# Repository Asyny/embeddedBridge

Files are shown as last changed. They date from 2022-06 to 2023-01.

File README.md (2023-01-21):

# embeddedBridge

Develop and test your own embedded system without the need to build a dedicated testbench. It is as easy as following three steps:
1. Connect your device under test to the corresponding GPIOs of the embeddedBridge (see: [Features](#Features))
2. Connect the embeddedBridge to your PC
3. Send commands automatically or manually via the serial connection to the embeddedBridge and thus your device

## Features 

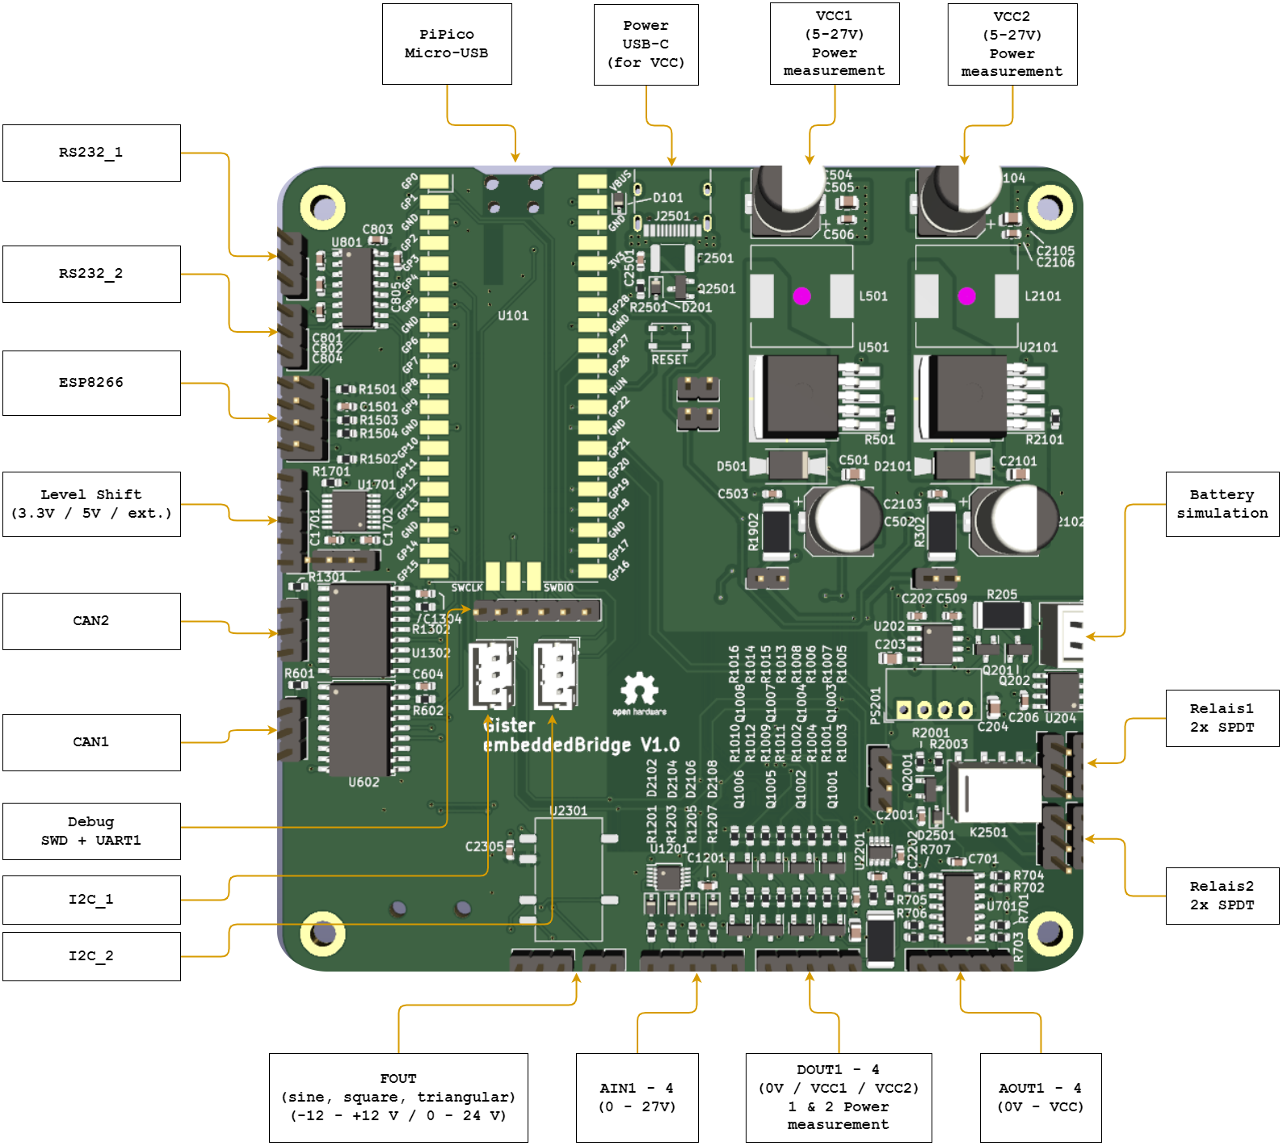
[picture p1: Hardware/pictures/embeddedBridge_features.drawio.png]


- 4x DOUT (2x 0 - 24 V)
- 4x AOUT (0 - 24 V)
- 4x AIN (max. 27 V)
- 1x FOUT
- 2x Relais (2x SPDT)
- 4x Level shift
- 2x RS232
- 2x CAN
- 1x Battery sim
- ESP8266 interface
- SD card
- EEPROM

## Update

- Download the .uf2 from the newest [release](https://github.com/Asyny/embeddedBridge/releases) assets
- Connect the embeddedBridge via micro USB to your PC
- Press the RESET button and the BOOTSEL simultaneously
- Let go of the RESET and afterwards the BOOTSEL button
- Move the .uf2 into the newly connected USB Drive

## Automatic vs Manual mode

The embeddedBridge will start in the automatic mode where it expects SCPI like commands. If you want to switch to the manual mode where a menu is printed on the serial interface, then you can send the command "SYStem:COMmand:INput MENU". To switch back to the automatic mode, you simple need to exit the menu.

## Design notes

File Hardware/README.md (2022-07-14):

# embeddedBridge_HW
THIS PROJECT IS UNDER CONSTRUCTION, IT WILL NOT WORK AS INTENDED!

## Introduction
The embeddedBridge provides an easy way to test your own embedded devices. It comes with an great amount of features with makes it compatible to a lot devices.

This is the Hardware repository. If you are looking fore the Software repository click [here](https://github.com/Asyny/embeddedBridge).

### Features
- based on Raspberry Pi Pico
- 2x variable powersuppies [XL6009]
  - voltage and current measurement [INA219]
- 4x switched output for powersuppies
  - 2x with voltage and current measurement [INA219]
- 1x battery simulation
  - source and sink current [MCP4725]
  - voltage and current measurement [INA219]
- 4x anlog inputs [ADS1115] (16-bit ADC)
- 4x analog ouput [MCP4728] (12-bit DAC)
  - amplified for a max of +24V
- 1x DDS output [AD9833]
  - amplified for a max of +-12V or +24V
  - variable offset [MCP4725]
- 2x CAN [MCP2515]
- 4x digital I/O with level shift
- 2x DPDT Relais
- 2x UART
- 1x ESP8266 header
- 1x SD Card
- 1x 32K EEPROM

## Production
The [Releases](https://github.com/Asyny/embeddedBridge_HW/releases) contain Gerber and Assembly files for [JLCPCB](https://jlcpcb.com/).
An HTML BOM which makes manual assembly easy, is included too.

## Contributing
If you want to contribute, please fork the repo and create a pull request. Thanks for your participation!

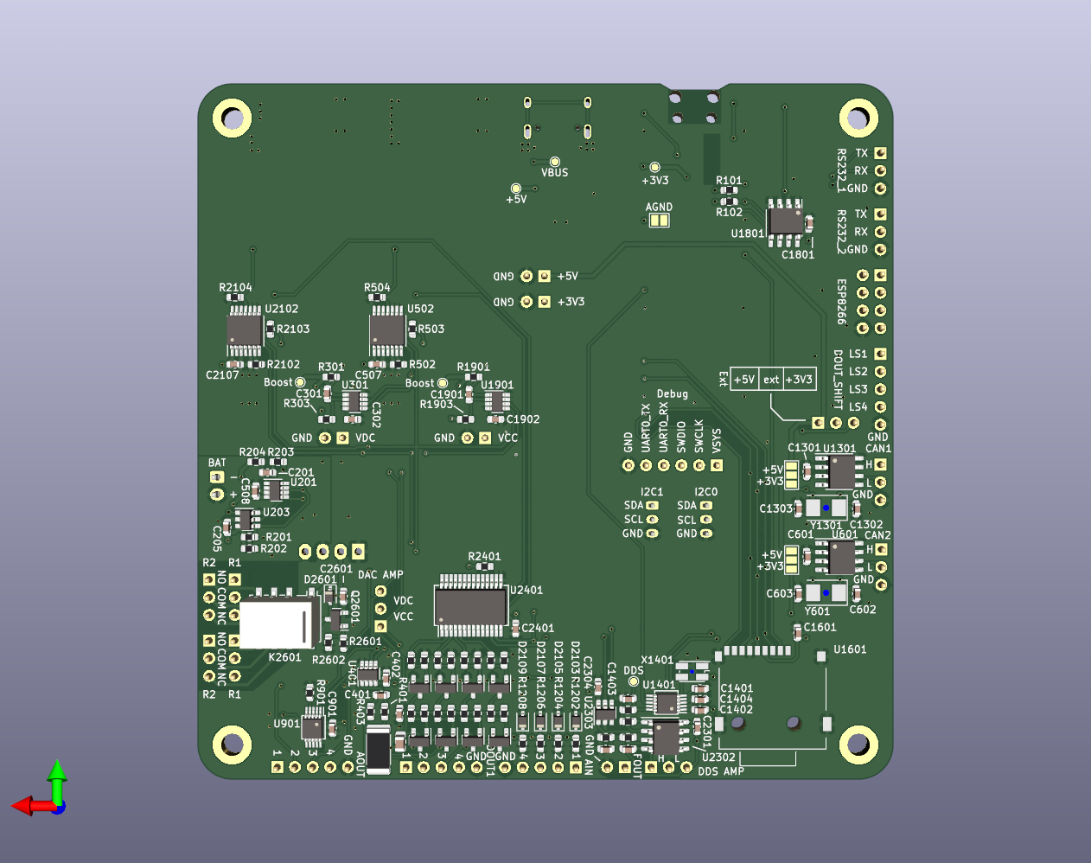
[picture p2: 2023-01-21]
Hardware/pictures/embeddedBridge_back.png

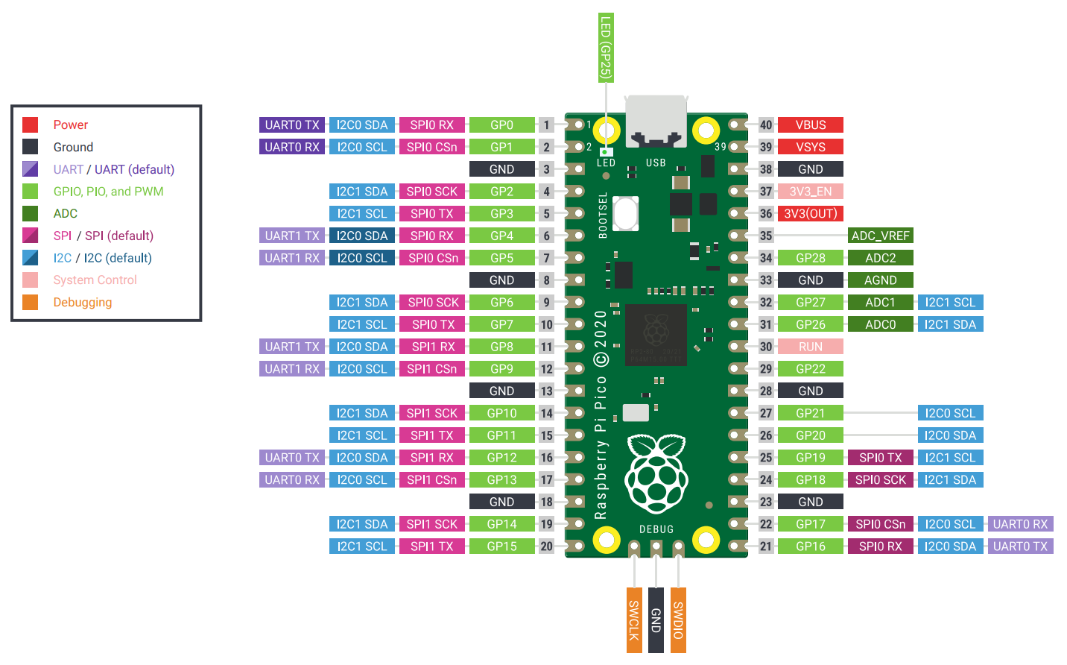
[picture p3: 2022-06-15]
Hardware/pictures/PiPico.PNG

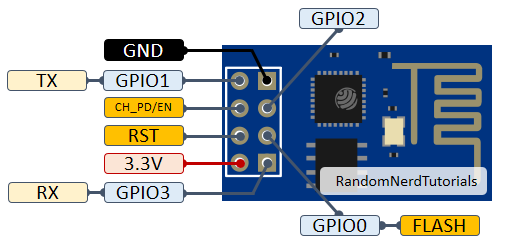
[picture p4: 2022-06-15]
Hardware/pictures/ESP8266-01.PNG

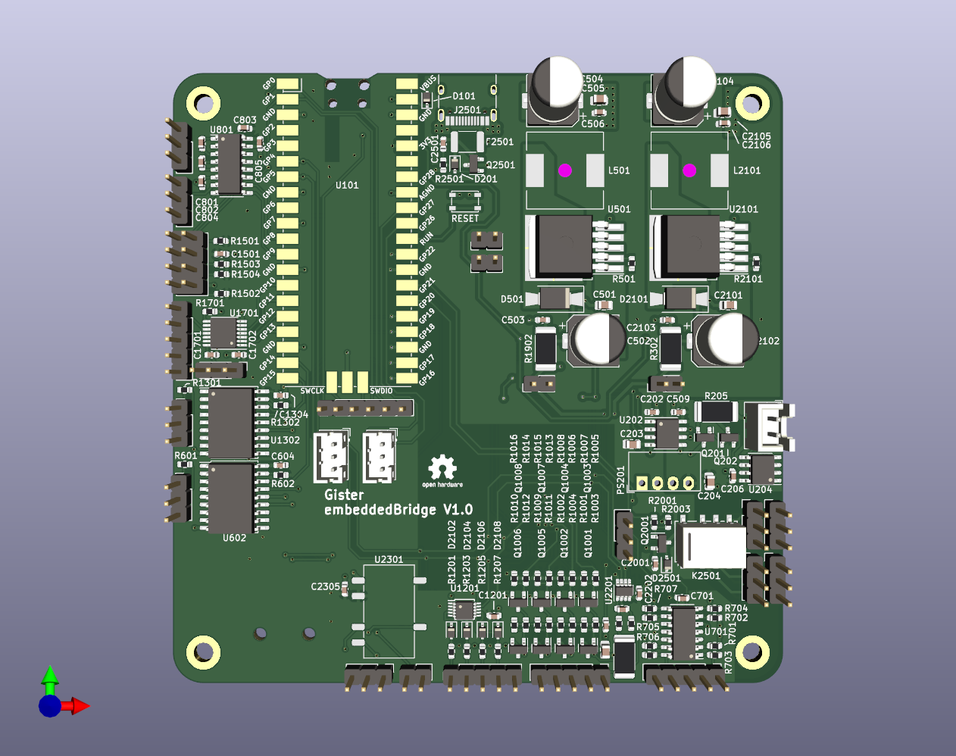
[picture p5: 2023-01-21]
Hardware/pictures/embeddedBridge_front.png

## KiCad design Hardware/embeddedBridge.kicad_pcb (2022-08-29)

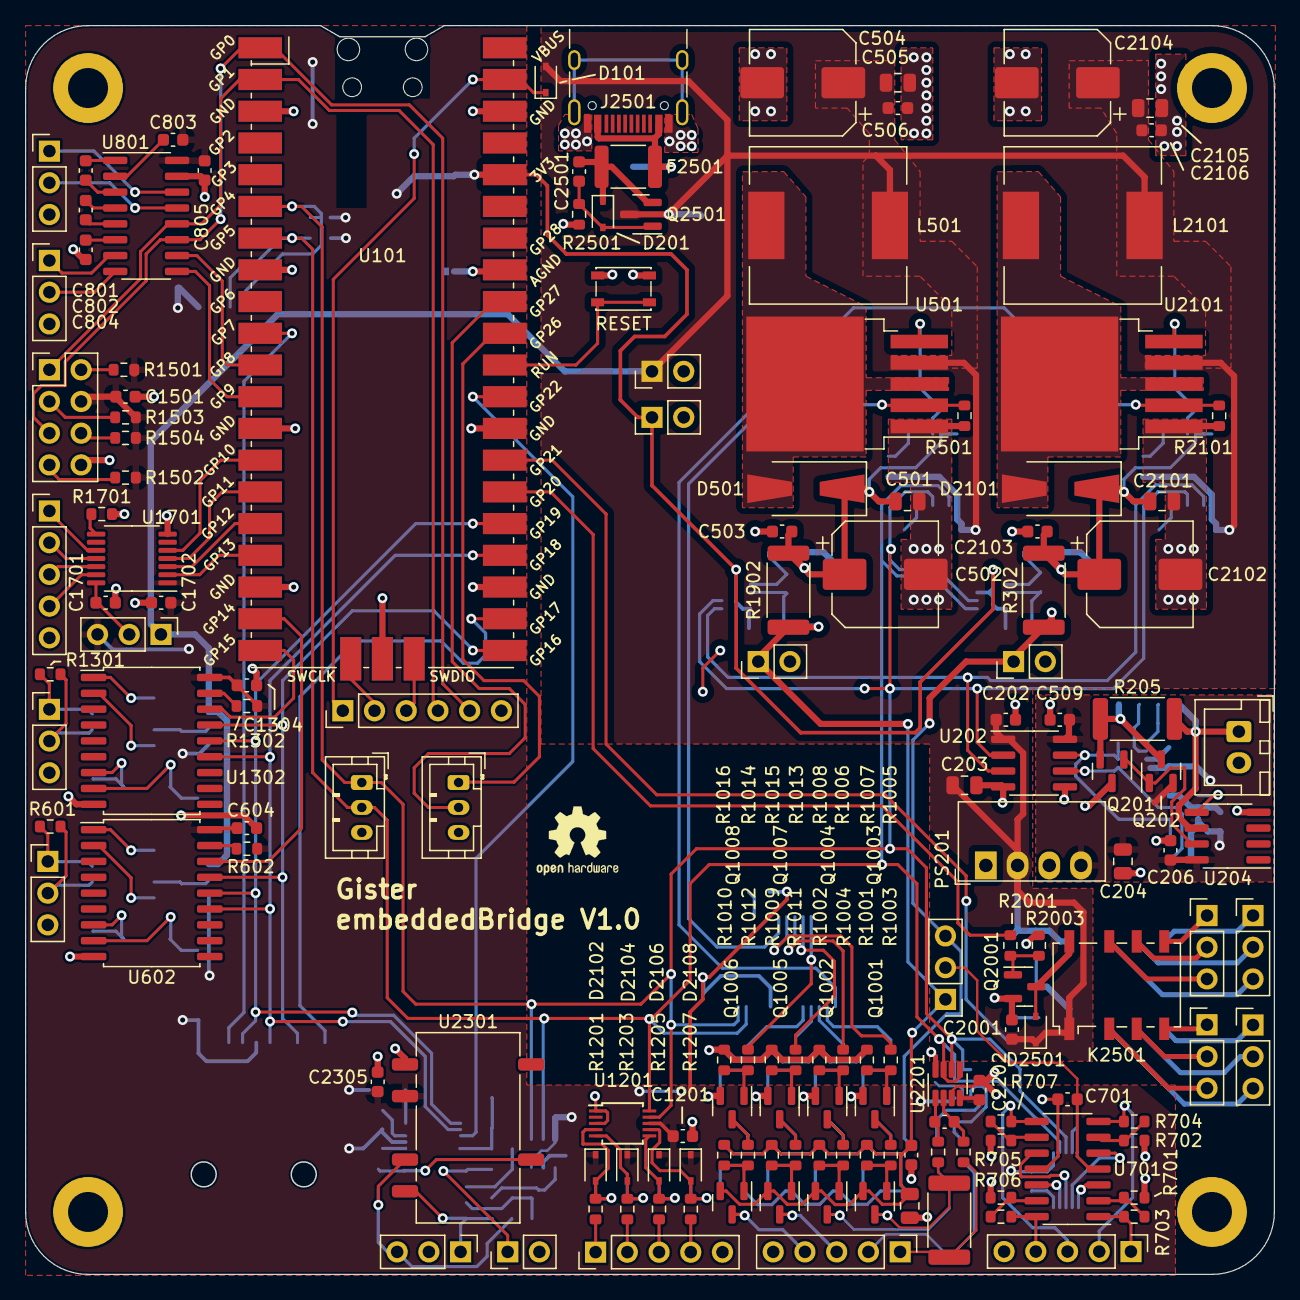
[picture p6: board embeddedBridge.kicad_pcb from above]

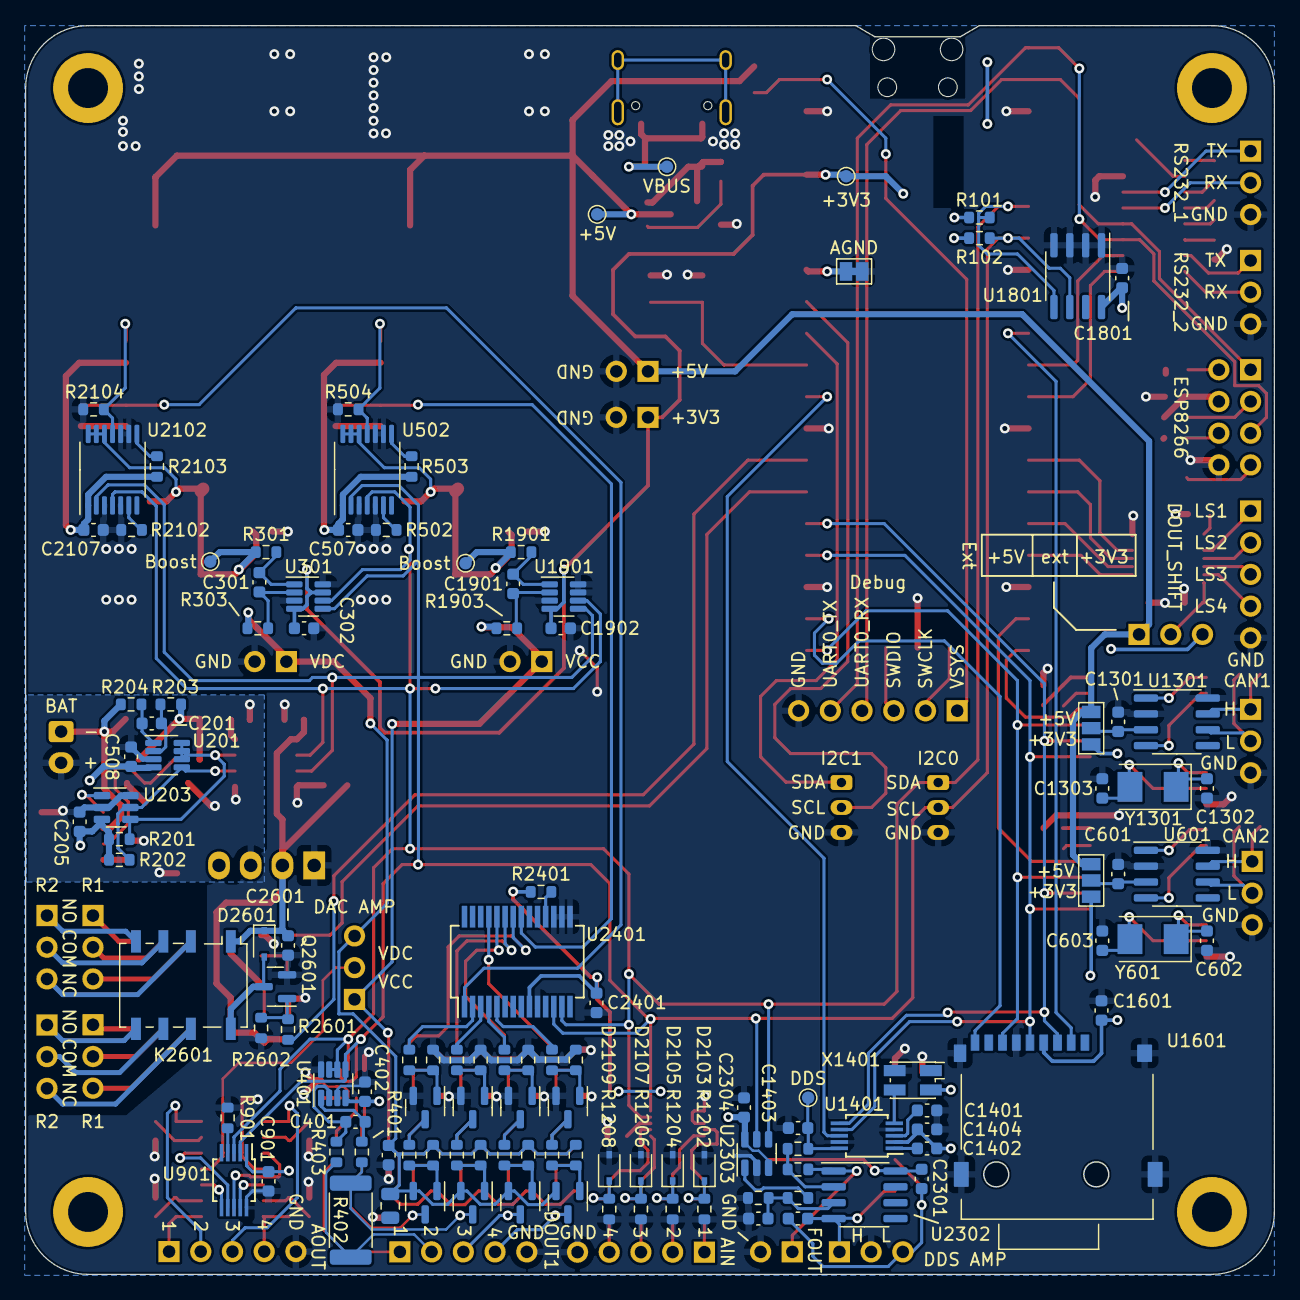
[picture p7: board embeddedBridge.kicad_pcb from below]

Board: 2 copper layers, 100.0 x 100.0 mm, 276 parts (122 on the bottom side), 189 nets.

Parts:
C201, C202, C205, C206, C301, C302, C401, C402, C503, C506, C507, C508, C509, C601, C604, C701, C801, C802, C803, C804, C805, C901, C1001, C1101, C1201, C1301, C1304, C1401, C1404, C1501, C1601, C1701, C1702, C1801, C1901, C1902, C2001, C2103, C2106, C2107, C2201, C2202, C2301, C2302, C2304, C2305, C2401, C2501, C2601: 100n; C_0603_1608Metric
C203, C204, C501, C505, C1002, C1102, C2101, C2105: 1u; C_0805_2012Metric
C502, C2102: 220u; CP_Elec_8x10
C504, C2104: 47u; CP_Elec_8x10
C602, C603, C1302, C1303: 22p; C_0603_1608Metric
C1402: 10n; C_0603_1608Metric
C1403: 20p; C_0603_1608Metric
C2303: 680n; C_0603_1608Metric
D101, D201, D2102, D2103, D2104, D2105, D2106, D2107, D2108, D2109, D2501, D2601: 1N5819; D_SOD-323
D501, D2101: D_Schottky; D_SMA-SMB_Universal_Handsoldering
F2501: Polyfuse; Fuse_1812_4532Metric
H101, H102, H103, H104: MountingHole_Pad; MountingHole_3.2mm_M3_DIN965_Pad
J101: AOUT; PinHeader_1x05_P2.54mm_Vertical
J102: I2C1; JST_PH_B3B-PH-K_1x03_P2.00mm_Vertical
J103: I2C0; JST_PH_B3B-PH-K_1x03_P2.00mm_Vertical
J104: Debug; PinHeader_1x06_P2.54mm_Vertical
J105: VCC; PinHeader_1x02_P2.54mm_Vertical
J106: DOUT1; PinHeader_1x05_P2.54mm_Vertical
J107: FOUT; PinHeader_1x02_P2.54mm_Vertical
J108: CAN1; PinHeader_1x03_P2.54mm_Vertical
J109: CAN2; PinHeader_1x03_P2.54mm_Vertical
J110: VDC; PinHeader_1x02_P2.54mm_Vertical
J111: R1_1; PinHeader_1x03_P2.54mm_Vertical
J112: R1_2; PinHeader_1x03_P2.54mm_Vertical
J113: R2_1; PinHeader_1x03_P2.54mm_Vertical
J114: R2_2; PinHeader_1x03_P2.54mm_Vertical
J115: RS232_2; PinHeader_1x03_P2.54mm_Vertical
J116: RS232_1; PinHeader_1x03_P2.54mm_Vertical
J117: +3V3; PinHeader_1x02_P2.54mm_Vertical
J118: +5V; PinHeader_1x02_P2.54mm_Vertical
J201: BAT; JST_XH_B2B-XH-A_1x02_P2.50mm_Vertical
J1201: AIN; PinHeader_1x05_P2.54mm_Vertical
J1501: ESP8266; PinHeader_2x04_P2.54mm_Vertical
J1701: DOUT_SHIFT; PinHeader_1x05_P2.54mm_Vertical
J2501: USB_C_Receptacle_USB2.0; USB_C_Receptacle_HRO_TYPE-C-31-M-12
JP101: AGND; SolderJumper-2_P1.3mm_Bridged_Pad1.0x1.5mm
JP601, JP1301: SolderJumper_3_Open; SolderJumper-3_P1.3mm_Open_Pad1.0x1.5mm_NumberLabels
JP701: DAC AMP; PinHeader_1x03_P2.54mm_Vertical
JP1701: Ext; PinHeader_1x03_P2.54mm_Vertical
JP2301: DDS AMP; PinHeader_1x03_P2.54mm_Vertical
K2501, K2601: G6K-2F-Y; Relay_DPDT_Omron_G6K-2F-Y
L501, L2101: 33uH; L_12x12mm_H8mm
PS201: 1S4E_0505S1U; Converter_DCDC_Murata_MEE1SxxxxSC_THT
Q201: Q_NPN_BCE; SOT-23
Q202: Q_PNP_BCE; SOT-23
Q1001, Q1002, Q1005, Q1006, Q1101, Q1102, Q1105, Q1106, Q2501: Q_PMOS_GSD; SOT-23
Q1003, Q1004, Q1007, Q1008, Q1103, Q1104, Q1107, Q1108: MMBT3904; SOT-23
Q2001, Q2601: Q_NMOS_GSD; SOT-23
R101, R102, R201, R202, R901, R2301: 4k7; R_0603_1608Metric
R203, R204, R301, R303, R401, R403, R1901, R1903, R2201, R2203: 10R; R_0603_1608Metric
R205, R302, R402, R1902, R2202: 100R; R_2512_6332Metric
R501, R502, R503, R602, R701, R702, R705, R706, R1001, R1002, R1005, R1006, R1009, R1010, R1013, R1014, R1101, R1102, R1105, R1106, R1109, R1110, R1113, R1114, R1302, R1501, R1502, R1503, R1504, R1701, R2001, R2101, R2102, R2103, R2304, R2401, R2601: 10k; R_0603_1608Metric
R504, R2104: 470R; R_0603_1608Metric
R601, R1301: 120R; R_0603_1608Metric
R703, R704, R707, R708: 68k; R_0603_1608Metric
R1003, R1004, R1007, R1008, R1011, R1012, R1015, R1016, R1103, R1104, R1107, R1108, R1111, R1112, R1115, R1116, R2003, R2501, R2602: 100k; R_0603_1608Metric
R1201, R1203, R1205, R1207: 12k; R_0603_1608Metric
R1202, R1204, R1206, R1208: 1k5; R_0603_1608Metric
R2302: 39k; R_0603_1608Metric
R2303: 1k; R_0603_1608Metric
SW101: RESET; SW_SPST_PTS810
TP101: +3V3; TestPoint_Pad_D1.0mm
TP102: DDS; TestPoint_Pad_D1.0mm
TP201: VBUS; TestPoint_Pad_D1.0mm
TP202: +5V; TestPoint_Pad_D1.0mm
TP501, TP2101: Boost; TestPoint_Pad_D1.0mm
U101: Pico; RPi_Pico_SMD_TH
U201, U301, U401, U1901, U2201: INA219AxDCN; SOT-23-8
U202: ISO1540; SOIC-8_3.9x4.9mm_P1.27mm
U203, U2303: MCP4725xxx-xCH; SOT-23-6
U204, U2302: Opamp_Dual; SOIC-8_3.9x4.9mm_P1.27mm
U501, U2101: XL6009; TO-263-5_TabPin3
U502, U2102: MCP45HV31-ST; TSSOP-14_4.4x5mm_P0.65mm
U601, U1301: TJA1051T-3; SOIC-8_3.9x4.9mm_P1.27mm
U602, U1302: MCP2515-xSO; SOIC-18W_7.5x11.6mm_P1.27mm
U701: LM324; SOIC-14_3.9x8.7mm_P1.27mm
U801: MAX3232; SOIC-16_3.9x9.9mm_P1.27mm
U901: MCP4728; MSOP-10_3x3mm_P0.5mm
U1201: ADS1115IDGS; TSSOP-10_3x3mm_P0.5mm
U1401: AD9833xRM; MSOP-10_3x3mm_P0.5mm
U1601: TF-01A; FT-01A
U1701: TXB0104PW; TSSOP-14_4.4x5mm_P0.65mm
U1801: 24LC32; SOIC-8_3.9x4.9mm_P1.27mm
U2301: PDS1-M; PSD1
U2401: MCP23017_SS; SSOP-28_5.3x10.2mm_P0.65mm
X1401: XO32; Oscillator_SMD_EuroQuartz_XO32-4Pin_3.2x2.5mm_HandSoldering
Y601, Y1301: 8MHz; Crystal_SMD_5032-2Pin_5.0x3.2mm

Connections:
+3V3: C302.1, C402.1, C604.1, C803.1, C805.1, C901.1, C1201.1, C1304.1, C1402.1, C1404.1, C1501.1, C1601.1, C1702.1, C1801.1, C1902.1, C2202.1, C2304.1, C2305.1, C2401.1, D2102.1 (K), D2104.1 (K), D2106.1 (K), D2108.1 (K), J117.1, J1501.4, JP601.1 (A), JP1301.1 (A), JP1701.3 (B), R101.2, R102.2, R602.1, R1302.1, R1501.1, R1502.1, R1503.2, R1504.2, R2401.1, TP101.1, U101.36 (3V3), U301.4 (VS), U301.7 (A0), U401.4 (VS), U602.18 (VDD), U801.16 (VCC), U901.1 (VDD), U1201.8 (VDD), U1302.18 (VDD), U1401.2 (VDD), U1601.4 (VDD), U1701.1 (VCCA), U1801.8 (VCC), U1901.4 (VS), U2201.4 (VS), U2301.2 (Vin), U2303.3 (VDD), U2303.6 (A0), U2401.9 (VDD), X1401.4 (V+)
+5V: C202.1, C203.1, C504.1, C505.1, C506.1, C507.1, C2001.1, C2104.1, C2105.1, C2106.1, C2107.1, C2601.1, D101.2 (A), D2501.1 (K), D2601.1 (K), J118.1, JP601.3 (B), JP1301.3 (B), JP1701.1 (A), K2501.1, K2601.1, L501.1, L2101.1, PS201.2 (+Vin), Q2501.3 (D), R503.2, R2103.2, TP202.1, U202.1 (VCC1), U501.4 (VIN), U502.1 (VL), U2101.4 (VIN), U2102.1 (VL)
+5VD: C204.1, C205.1, C206.1, C508.1, C509.1, PS201.4 (+Vout), Q201.2 (C), R201.1, R202.1, U201.4 (VS), U202.8 (VCC2), U203.3 (VDD), U204.8 (V+)
/AMP1/IN1+: U701.3 (+), U901.6 (VOUTA)
/AMP1/IN2+: U701.5 (+), U901.7 (VOUTB)
/AMP1/IN3+: U701.10 (+), U901.8 (VOUTC)
/AMP1/IN4+: U701.12 (+), U901.9 (VOUTD)
/AMP1/OUT1: J101.1, R703.2, U701.1
/AMP1/OUT2: J101.2, R704.2, U701.7
/AMP1/OUT3: J101.3, R707.2, U701.8
/AMP1/OUT4: J101.4, R708.2, U701.14
/AMP_offset/IN: C1403.1, R2301.2, TP102.1, U1401.10 (VOUT)
/AMP_offset/OUT: J107.1, R2302.2, U2302.1
/Battery/BAT+: J201.1, R204.1, R205.2, U204.6 (-)
/Battery/BAT+_: Q201.3 (E), Q202.2 (C), R203.1, R205.1
/Battery/SCL_: R202.2, U201.5 (SCL), U202.6 (SCL2), U203.5 (SCL)
/Battery/SDA_: R201.2, U201.6 (SDA), U201.7 (A0), U201.8 (A1), U202.7 (SDA2), U203.4 (SDA)
/CAN1/CANH: J108.1, R1301.2, U1301.7 (CANH)
/CAN1/CANL: J108.2, R1301.1, U1301.6 (CANL)
/CAN2/CANH: J109.1, R601.2, U601.7 (CANH)
/CAN2/CANL: J109.2, R601.1, U601.6 (CANL)
/CD_SD: U101.22 (GPIO17), U1601.9 (CD)
/Cu1+: C501.1, C502.1, C503.1, D501.1 (K), R1901.1, R1902.1, TP501.1, U502.12 (P0W), U502.13 (P0A), U502.14 (V+)
/Cu2+: C2101.1, C2102.1, C2103.1, D2101.1 (K), R301.1, R302.1, TP2101.1, U2102.12 (P0W), U2102.13 (P0A), U2102.14 (V+)
/Cu3+: Q1002.3 (D), Q1102.3 (D), R401.1, R402.1
/Cu3-: J106.2, R402.2, R403.1
/Cu4+: Q1001.3 (D), Q1101.3 (D), R2201.1, R2202.1
/Cu4-: J106.1, R2202.2, R2203.1
/DAC1/LDAC: R901.1, U901.4 (~LDAC)
/DOUT1_LS: U101.14 (GPIO10), U1701.5 (A4)
/DOUT2_LS: U101.15 (GPIO11), U1701.4 (A3)
/DOUT3_LS: U101.16 (GPIO12), U1701.3 (A2)
/DOUT4_LS: U101.17 (GPIO13), U1701.2 (A1)
/ESP8266/EN: J1501.2, R1501.2
/ESP8266/IO0: J1501.6, R1504.1
/ESP8266/IO2: J1501.7, R1502.2
/ESP8266/RST: J1501.3, R1503.1
/I2C0_SCL: J103.2, R102.1, U101.7 (GPIO5), U202.3 (SCL1), U301.5 (SCL), U401.5 (SCL), U502.2 (SCL), U901.2 (SCL), U1201.10 (SCL), U1801.6 (SCL), U1901.5 (SCL), U2102.2 (SCL), U2201.5 (SCL), U2201.7 (A0), U2303.5 (SCL), U2401.12 (SCK)
/I2C0_SDA: J103.1, R101.1, U101.6 (GPIO4), U202.2 (SDA1), U301.6 (SDA), U401.6 (SDA), U401.7 (A0), U502.4 (SDA), U901.3 (SDA), U1201.9 (SDA), U1801.5 (SDA), U1901.6 (SDA), U2102.4 (SDA), U2201.6 (SDA), U2303.4 (SDA), U2401.13 (SDA)
/I2C1_SCL: J102.2, U101.32 (GPIO27_ADC1)
/I2C1_SDA: J102.1, U101.31 (GPIO26_ADC0)
/IO_Expander/GPA1: R1005.1, U2401.22 (GPA1)
/IO_Expander/GPA2: R1006.1, U2401.23 (GPA2)
/IO_Expander/GPA3: R1013.1, U2401.24 (GPA3)
/IO_Expander/GPA4: R1014.1, U2401.25 (GPA4)
/IO_Expander/GPB1: R1105.1, U2401.2 (GPB1)
/IO_Expander/GPB2: R1106.1, U2401.3 (GPB2)
/IO_Expander/GPB3: R1113.1, U2401.4 (GPB3)
/IO_Expander/GPB4: R1114.1, U2401.5 (GPB4)
/Level Shift/OE: R1701.1, U1701.8 (OE)
/Power1/FB: R504.1, U501.5 (FB), U502.11 (P0B)
/Power1/SW: D501.2 (A), L501.2, U501.3 (SW)
/Power2/FB: R2104.1, U2101.5 (FB), U2102.11 (P0B)
/Power2/SW: D2101.2 (A), L2101.2, U2101.3 (SW)
/RUN: SW101.1 (A), U101.30 (RUN)
/Relais1: R2001.1, U101.26 (GPIO20)
/Relais1/COM1: J111.2, K2501.3
/Relais1/COM2: J112.2, K2501.6
/Relais1/NC1: J111.3, K2501.2
/Relais1/NC2: J112.3, K2501.7
/Relais1/NO1: J111.1, K2501.4
/Relais1/NO2: J112.1, K2501.5
/Relais2: R2601.1, U101.27 (GPIO21)
/Relais2/COM1: J113.2, K2601.3
/Relais2/COM2: J114.2, K2601.6
/Relais2/NC1: J113.3, K2601.2
/Relais2/NC2: J114.3, K2601.7
/Relais2/NO1: J113.1, K2601.4
/Relais2/NO2: J114.1, K2601.5
/SPI0_CS_CAN1: U101.20 (GPIO15), U1302.16 (~CS)
/SPI0_CS_CAN2: U101.19 (GPIO14), U602.16 (~CS)
/SPI0_CS_DDS: U101.29 (GPIO22), U1401.8 (~FSYNC)
/SPI0_CS_SD: U101.10 (GPIO7), U1601.2 (CDDAT3(CS))
/SPI0_MISO: U101.21 (GPIO16), U602.15 (SO), U1302.15 (SO), U1601.7 (DAT0(D0))
/SPI0_MOSI: U101.25 (GPIO19), U602.14 (SI), U1302.14 (SI), U1401.6 (SDATA), U1601.3 (CMD(DI))
/SPI0_SCK: U101.24 (GPIO18), U602.13 (SCK), U1302.13 (SCK), U1401.7 (SCLK), U1601.5 (CLK(SCLK))
/SWCLK: J104.2, U101.41 (SWCLK)
/SWDIO: J104.3, U101.43 (SWDIO)
/Switch1/DOUT3: J106.3, Q1005.3 (D), Q1105.3 (D)
/Switch1/DOUT4: J106.4, Q1006.3 (D), Q1106.3 (D)
/UART0_RX: J104.4, J1501.1, U101.2 (GPIO1), U801.12 (R1OUT)
/UART0_TX: J104.5, J1501.5, U101.1 (GPIO0), U801.11 (T1IN)
/UART1_RX: U101.12 (GPIO9), U801.9 (R2OUT)
/UART1_TX: U101.11 (GPIO8), U801.10 (T2IN)
/UART to RS232/RX1: J116.2, U801.13 (R1IN)
/UART to RS232/RX2: J115.2, U801.8 (R2IN)
/UART to RS232/TX1: J116.1, U801.14 (T1OUT)
/UART to RS232/TX2: J115.1, U801.7 (T2OUT)
/USB/VBUS: F2501.1, J2501.A4 (VBUS), J2501.A9 (VBUS), J2501.B4 (VBUS), J2501.B9 (VBUS), TP201.1
/USB/VBUS_FUSED: C2501.1, D201.1 (K), F2501.2, Q2501.2 (S)
/VCC_EN: R501.1, U501.2 (EN), U2401.21 (GPA0)
/VDC_EN: R2101.1, U2101.2 (EN), U2401.1 (GPB0)
/VSYS: D101.1 (K), J104.1, U101.39 (VSYS)
GND: C202.2, C203.2, C302.2, C402.2, C501.2, C502.2, C503.2, C504.2, C505.2, C506.2, C507.2, C601.2, C602.2, C603.2, C604.2, C701.2, C804.1, C805.2, C901.2, C1001.2, C1002.2, C1101.2, C1102.2, C1201.2, C1301.2, C1302.2, C1303.2, C1304.2, C1401.2, C1403.2, C1404.2, C1501.2, C1601.2, C1701.2, C1702.2, C1801.2, C1902.2, C2001.2, C2101.2, C2102.2, C2103.2, C2104.2, C2105.2, C2106.2, C2107.2, C2202.2, C2303.2, C2304.2, C2305.2, C2401.2, C2601.2, D2103.2 (A), D2105.2 (A), D2107.2 (A), D2109.2 (A), J101.5, J102.3, J103.3, J104.6, J105.2, J106.5, J107.2, J108.3, J109.3, J110.2, J115.3, J116.3, J117.2, J118.2, J1201.5, J1501.8, J1701.5, J2501.A1 (GND), J2501.A12 (GND), J2501.B1 (GND), J2501.B12 (GND), JP101.1 (A), JP2301.2 (C), PS201.1 (-Vin), Q1003.2 (E), Q1004.2 (E), Q1007.2 (E), Q1008.2 (E), Q1103.2 (E), Q1104.2 (E), Q1107.2 (E), Q1108.2 (E), Q2001.2 (S), Q2601.2 (S), R501.2, R502.2, R504.2, R701.1, R702.1, R705.1, R706.1, R901.2, R1007.2, R1008.2, R1015.2, R1016.2, R1107.2, R1108.2, R1115.2, R1116.2, R1202.2, R1204.2, R1206.2, R1208.2, R1701.2, R2003.2, R2101.2, R2102.2, R2104.2, R2304.2, R2501.2, R2602.2, SW101.2 (B), U101.3 (GND), U101.8 (GND), U101.13 (GND), U101.18 (GND), U101.23 (GND), U101.28 (GND), U101.38 (GND), U101.42 (GND), U202.4 (GND1), U301.3 (GND), U301.8 (A1), U401.3 (GND), U401.8 (A1), U501.1 (GND), U502.3 (A1), U502.5 (A0), U502.9 (DGND), U502.10 (V-), U601.2 (GND), U601.8 (S), U602.9 (VSS), U701.11 (V-), U801.15 (GND), U901.10 (VSS), U1201.1 (ADDR), U1201.3 (GND), U1301.2 (GND), U1301.8 (S), U1302.9 (VSS), U1401.4 (DGND), U1401.9 (AGND), U1601.6 (VSS), U1601.10 (GND), U1601.11 (GND), U1601.12 (GND), U1601.13 (GND), U1701.7 (GND), U1801.1 (A0), U1801.2 (A1), U1801.3 (A2), U1801.4 (GND), U1901.3 (GND), U1901.7 (A0), U1901.8 (A1), U2101.1 (GND), U2102.3 (A1), U2102.5 (A0), U2102.9 (DGND), U2102.10 (V-), U2201.3 (GND), U2201.8 (A1), U2301.1 (GND), U2303.2 (VSS), U2401.10 (VSS), U2401.15 (A0), U2401.16 (A1), U2401.17 (A2), X1401.2 (GND)
GNDA: JP101.2 (B), U101.33 (AGND)
GNDD: C204.2, C205.2, C206.2, C508.2, C509.2, J201.2, PS201.3 (-Vout), Q202.3 (E), U201.3 (GND), U202.5 (GND2), U203.2 (VSS), U203.6 (A0), U204.4 (V-)
unnamed: C201.1, R203.2, U201.2 (IN-)
unnamed: C201.2, R204.2, U201.1 (IN+)
unnamed: C301.1, R301.2, U301.1 (IN+)
unnamed: C301.2, R303.2, U301.2 (IN-)
unnamed: C401.1, R401.2, U401.1 (IN+)
unnamed: C401.2, R403.2, U401.2 (IN-)
unnamed: C601.1, JP601.2 (C), U601.3 (VCC)
unnamed: C602.1, U602.7 (OSC2), Y601.1
unnamed: C603.1, U602.8 (OSC1), Y601.2
unnamed: C701.1, JP701.2 (C), U701.4 (V+)
unnamed: C801.1, U801.3 (C1-)
unnamed: C801.2, U801.1 (C1+)
unnamed: C802.1, U801.5 (C2-)
unnamed: C802.2, U801.4 (C2+)
unnamed: C803.2, U801.2 (VS+)
unnamed: C804.2, U801.6 (VS-)
unnamed: C1301.1, JP1301.2 (C), U1301.3 (VCC)
unnamed: C1302.1, U1302.7 (OSC2), Y1301.1
unnamed: C1303.1, U1302.8 (OSC1), Y1301.2
unnamed: C1401.1, U1401.3 (CAP/2.5V)
unnamed: C1402.2, U1401.1 (COMP)
unnamed: C1701.1, JP1701.2 (C), U1701.14 (VCCB)
unnamed: C1901.1, R1901.2, U1901.1 (IN+)
unnamed: C1901.2, R1903.2, U1901.2 (IN-)
unnamed: C2201.1, R2201.2, U2201.1 (IN+)
unnamed: C2201.2, R2203.2, U2201.2 (IN-)
unnamed: C2301.1, U2301.7 (+Vo), U2302.8 (V+)
unnamed: C2301.2, C2302.1, JP2301.3 (B), U2301.4 (0V)
unnamed: C2302.2, JP2301.1 (A), U2301.5 (-Vo), U2302.4 (V-)
unnamed: C2303.1, R2303.1, R2304.1, U2302.3 (+)
unnamed: C2501.2, D201.2 (A), Q2501.1 (G), R2501.1
unnamed: D2102.2 (A), D2103.1 (K), R1201.2, R1202.1, U1201.4 (AIN0)
unnamed: D2104.2 (A), D2105.1 (K), R1203.2, R1204.1, U1201.5 (AIN1)
unnamed: D2106.2 (A), D2107.1 (K), R1205.2, R1206.1, U1201.6 (AIN2)
unnamed: D2108.2 (A), D2109.1 (K), R1207.2, R1208.1, U1201.7 (AIN3)
unnamed: D2501.2 (A), K2501.8, Q2001.3 (D)
unnamed: D2601.2 (A), K2601.8, Q2601.3 (D)
unnamed: J1201.1, R1201.1
unnamed: J1201.2, R1203.1
unnamed: J1201.3, R1205.1
unnamed: J1201.4, R1207.1
unnamed: J1701.1, U1701.10 (B4)
unnamed: J1701.2, U1701.11 (B3)
unnamed: J1701.3, U1701.12 (B2)
unnamed: J1701.4, U1701.13 (B1)
unnamed: Q201.1 (B), Q202.1 (B), U204.7
unnamed: Q1001.1 (G), R1001.2, R1003.1
unnamed: Q1002.1 (G), R1002.2, R1004.1
unnamed: Q1003.1 (B), R1005.2, R1007.1
unnamed: Q1003.3 (C), R1003.2
unnamed: Q1004.1 (B), R1006.2, R1008.1
unnamed: Q1004.3 (C), R1004.2
unnamed: Q1005.1 (G), R1009.2, R1011.1
unnamed: Q1006.1 (G), R1010.2, R1012.1
unnamed: Q1007.1 (B), R1013.2, R1015.1
unnamed: Q1007.3 (C), R1011.2
unnamed: Q1008.1 (B), R1014.2, R1016.1
unnamed: Q1008.3 (C), R1012.2
unnamed: Q1101.1 (G), R1101.2, R1103.1
unnamed: Q1102.1 (G), R1102.2, R1104.1
unnamed: Q1103.1 (B), R1105.2, R1107.1
unnamed: Q1103.3 (C), R1103.2
unnamed: Q1104.1 (B), R1106.2, R1108.1
unnamed: Q1104.3 (C), R1104.2
unnamed: Q1105.1 (G), R1109.2, R1111.1
unnamed: Q1106.1 (G), R1110.2, R1112.1
unnamed: Q1107.1 (B), R1113.2, R1115.1
unnamed: Q1107.3 (C), R1111.2
unnamed: Q1108.1 (B), R1114.2, R1116.1
unnamed: Q1108.3 (C), R1112.2
unnamed: Q2001.1 (G), R2001.2, R2003.1
unnamed: Q2601.1 (G), R2601.2, R2602.1
unnamed: R502.1, U502.6 (~WLAT)
unnamed: R503.1, U502.8 (~SHDN)
unnamed: R602.2, U602.17 (~RESET)
unnamed: R701.2, R703.1, U701.2 (-)
unnamed: R702.2, R704.1, U701.6 (-)
unnamed: R705.2, R707.1, U701.9 (-)
unnamed: R706.2, R708.1, U701.13 (-)
unnamed: R1302.2, U1302.17 (~RESET)
unnamed: R2102.1, U2102.6 (~WLAT)
unnamed: R2103.1, U2102.8 (~SHDN)
unnamed: R2301.1, R2302.1, U2302.2 (-)
unnamed: R2303.2, U2303.1 (VOUT)
unnamed: R2401.2, U2401.18 (~RESET)
unnamed: U203.1 (VOUT), U204.5 (+)
unnamed: U601.1 (TXD), U602.1 (TXCAN)
unnamed: U601.4 (RXD), U602.2 (RXCAN)
unnamed: U1301.1 (TXD), U1302.1 (TXCAN)
unnamed: U1301.4 (RXD), U1302.2 (RXCAN)
unnamed: U1401.5 (MCLK), X1401.3 (OUT)
VCC: C1001.1, C1002.1, J105.1, JP701.1 (A), Q1001.2 (S), Q1002.2 (S), Q1005.2 (S), Q1006.2 (S), R1001.1, R1002.1, R1009.1, R1010.1, R1902.2, R1903.1
VDC: C1101.1, C1102.1, J110.1, JP701.3 (B), Q1101.2 (S), Q1102.2 (S), Q1105.2 (S), Q1106.2 (S), R302.2, R303.1, R1101.1, R1102.1, R1109.1, R1110.1

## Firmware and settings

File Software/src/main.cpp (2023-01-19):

#include <Arduino.h>

// custom libraries
#include "hardware.h"
#include "HAL.h"

#include "CommandHandling/CommandHandler.h"
#include "CommandHandling/InteractiveCommandHandler.h"
#include "CommandHandling/ScpiCommandHandler.h"

#include "DataHandling/DataHandler.h"


CommandHandler* commandHandler = nullptr;
DataHandler* dataHandler = nullptr;

void setup() {
	Debug.setDebugLevel(DEBUG_LEVEL);
	Debug.setDebugOutputStream(&DEBUG_SERIAL);

	HAL::getInstance()->initialize();

	commandHandler = new ScpiCommandHandler();
	dataHandler = new DataHandler();

	Debug.print(DBG_INFO, "\n>>> init done");
}

void selectCommandMenuSource(void) {
	if (DataModel::newMode != DataModel::CommandHandlerInputMode::IDLE) {
		if (commandHandler != nullptr)
				delete commandHandler;

		if (DataModel::newMode == DataModel::CommandHandlerInputMode::INTERACTIVE) {
			commandHandler = new SerialMenu::InteractiveCommandHandler();
		}
		else if (DataModel::newMode == DataModel::CommandHandlerInputMode::SCPI) {
			commandHandler = new ScpiCommandHandler();
		}

		commandHandler->setup();
		DataModel::newMode = DataModel::CommandHandlerInputMode::IDLE;
	}
}

void loop() {
	selectCommandMenuSource();

	commandHandler->process();
	dataHandler->process();
}

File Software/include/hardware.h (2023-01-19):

#ifndef HARDWARE_H
#define HARDWARE_H

// third party libraries
#include <Arduino.h>
#include <Arduino_DebugUtils.h>

#define DEBUG_SERIAL Serial1
#define DEBUG_LEVEL DBG_WARNING	// DBG_NONE, DBG_ERROR, DBG_WARNING, DBG_INFO, DBG_DEBUG, DBG_VERBOSE

// datasheets
//MCP45HV31 https://eu.mouser.com/datasheet/2/268/20005304A-347268.pdf

// Serial
#define SERIAL_BAUD 115200
// UART
#define UART0_BAUD 115200
#define UART0_TX 0
#define UART0_RX 1
#define UART1_BAUD 115200
#define UART1_TX 8
#define UART1_RX 9

// SPI
#define SPI0_SCK 18
#define SPI0_MOSI 19
#define SPI0_MISO 16
// SPI CS
#define AD9833_DDS_CS 22
#define MCP2515_CAN1_CS 15
#define MCP2515_CAN2_CS 14
#define SD_CS 7

// GPIOs
#define LED_PIN 25
#define RELAIS1_PIN 20
#define RELAIS2_PIN 21
#define LEVELSHIFT1_PIN 10
#define LEVELSHIFT2_PIN 11
#define LEVELSHIFT3_PIN 12
#define LEVELSHIFT4_PIN 13
#define AMP_HL 3
#define SD_CD 17

// I2C
#define I2C0_SDA 4
#define I2C0_SCL 5
#define I2C1_SDA 26
#define I2C1_SCL 27
// I2C Adresses
#define INA219_VCC_ADDR 0x40
#define INA219_VDC_ADDR 0x41
#define INA219_DOUT1_ADDR 0x42
#define INA219_DOUT2_ADDR 0x43
#define INA219_BAT_ADDR 0x4A
#define MCP23017_DOUT_ADDR 0x20	
//#define MCP4728_AOUT_ADDR 0x60	// ToDo: BUG same adress as MCP4725 Battery
#define MCP4725_BAT_ADDR 0x60 // AJxx=110000n, APxx=110001n, AQxx=110010n, ARxx=110011n
#define MCP4725_DDSOFFSET_ADDR 0x61
#define ADS1115_AIN_ADDR 0x48
#define EEPROM_ADDR 0x50
#define MCP45HV31_VCC_ADDR 0x3C
#define MCP45HV31_VDC_ADDR 0x3D	// ToDo: BUG same address as MCP45HV31_VCC_ADDR

// MCP23017 GPIOs
#define VCC_EN_PIN 0
#define VCC_DOUT1_PIN 1
#define VCC_DOUT2_PIN 2
#define VCC_DOUT3_PIN 3
#define VCC_DOUT4_PIN 4
//#define UNUSED 5
//#define UNUSED 6
//#define UNUSED 7
#define VDC_EN_PIN 8
#define VDC_DOUT1_PIN 9
#define VDC_DOUT2_PIN 10
#define VDC_DOUT3_PIN 11
#define VDC_DOUT4_PIN 12
//#define UNUSED 13
//#define UNUSED 14
//#define UNUSED 15

// Settings
#define VCC_VDC_MAX_VOLTAGE 27.0

#define MCP23017_MAX_PIN 15

#define AIN1_VOLTAGE_DEVIDER 9.1266
#define AIN2_VOLTAGE_DEVIDER 9.1266
#define AIN3_VOLTAGE_DEVIDER 9.1266
#define AIN4_VOLTAGE_DEVIDER 9.1266

#define FOUT_OFFSET_MULTIPLIER 160
#define BAT_MULTIPLIER 790
#define VCC_VOLTAGE_MULTIPLIER 4.561 // 1.25*(1+100k/4k7)=27.846V; max wiper (100k) = 127 -> 27.846 = 127, 0.219 = 1
#define VDC_VOLTAGE_MULTIPLIER 4.561

#define MENU_SERIAL Serial

#endif // HARDWARE_H

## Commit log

2022-08-29 add software
    [ADC.kicad_sch, AMP.kicad_sch, AMP_offset.kicad_sch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]
2022-12-12 set USB port as menu serial; fix AIN2_VOLTAGE_DEVIDER values
    [hardware.h]
2022-12-19 switch to debug serial interface
2022-12-19 add support to switch between SCPI and MENU SERIAL interface for sending commands
2022-12-20 set initial ADC gain to 1 instead of auto (auto is not supported)
2022-12-20 add SCPI command handling for ADC, relais, and level shift
2022-12-21 fix EOL handling for SCPI commands
    [ScpiCommandHandler.cpp, hardware.h, main.cpp]
2022-12-22 add error response to SCPI commads; minor improvements for serial
    [ScpiCommandHandler.cpp]
2023-01-09 add documentation of supported SCPI commands
    [EmbeddedBridgeScpiCommands.xlsx]
2023-01-20 moved commands to wiki
    [EmbeddedBridgeScpiCommands.xlsx]
